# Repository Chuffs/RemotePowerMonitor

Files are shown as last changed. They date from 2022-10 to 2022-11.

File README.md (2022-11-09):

# Remote Power Outage Detection & Alert System
This Github repository and project outlines the usage of an Arduino Based ESP8266 WiFi and Bluetooth Module along with a WaveShare SIM7000E NB-IoT / Cat-M / EDGE / GPRS Module in creating an alert system for a remote site power outage.

---

## Versions
- [V0.1a](#v01a)
- [V0.2a](#v02a) - Current Version
---

## Background
During the summer in outback Queensland, temperatures can exceed 50°C. ALong with the high temperatures weather can be rather sporadic, with sudden flash flooding and lightning storms. This can cause havoc with the electricity network with unplanned outages. A lot of properties in outback Queensland are far from any town and getting notified of a power outage is incredibly rare. In order to avoid rotten food in both fridges and freezers I wanted to create a device that could notify me of a power outage so that I could take appropriate action to save, or at least salvage, food and perishables at these remote locations.

## Initial Drawing of Idea
Simply put we needed a system that could detect the power outage which then alerted some form of microcontroller to then send an alert to myself to notify/warn of the power outage. In order to actually do this, in the case of a power outage, this system would need to be battery operated so that it could continue after power was removed from the site.

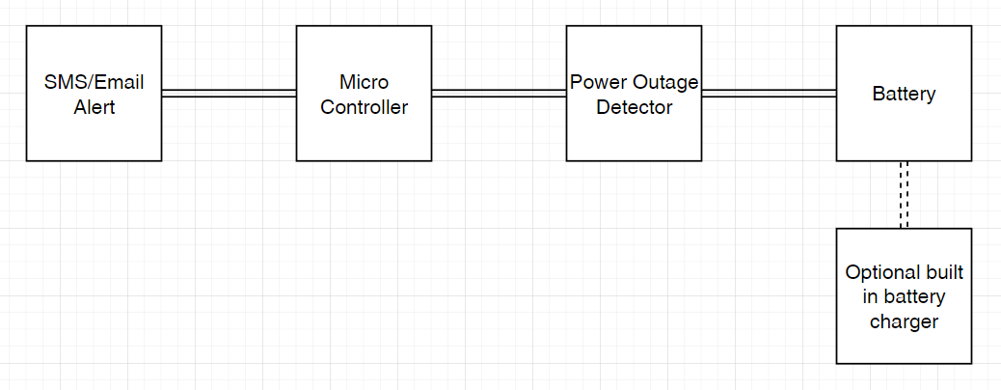
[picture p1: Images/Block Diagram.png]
Block Diagram of Project


# V0.1a
This version used the below components to detect and alert of a power outage.

- [WaveShare SIM7000E][def]
    - *Only LTE Capable module available in Australia at time of purchase*
- [ESP8266 WiFi Board - XC3082][def2]
    - *Small Footprint, Cheap cost and easy to access. Uses the Arduino library and IDE for ease of programming and debugging*
- [XC4502][def4] paired with an [XC4512][def5], a cheap and small footprint LiPo charger and 5v boost module.
- 10k - 10k voltage divider with a 5v Wall Plug into the analog pin of the ESP8266
- Telstra Cat-M SIM Card

## What went well?
- Proof of concept for sending an SMS on an external trigger (analog pin falling below a certain threshold)
- Footprint of prototype, could all be contained within a small jiffy type container.

## ~~Bugs~~ "Features" and what had to be improved on:
- Source of heat in the winter - The XC4502 and the XC4512 cannot be used simultaneously. Loading the battery caused the charger module to think that the battery needed charging and therefore pumped in more voltage causing parts to overheat.
- The usage of the 10k - 10k voltage divider was to ensure that the voltage going into the analog pin didn't exceed the maximum voltage. However, connecting the external 5v and the 5v boost module's ground together caused some strange behavior on the analog to digital conversion in code.
- The price of maintaining a cellular capable SIM was extortionate when considering the usage of this device would probably be a couple times a month during summer or rather 4-6 months of the year.

# V0.2a
This version included a multitude of updates making the system more reliable and user friendly, including a WebUI for configuring and customizing the alerts to be sent. The detection system also had an overhaul and the charging functionality was completely removed.

The code was changed to incorporate the deep sleep functionality of the ESP Family.

One additional part was added in this version - [LiteOn 4N25 Optocoupler][def7]. This allowed the 5v Wall Adapter to be completely separated and isolated from the ESP and Modem.

With testing complete a pcb prototype of this version was made - KiCAD Project Files can be found under this [folder][def8].

## What went well

## What needs improved on

Psuedo code or flow chart was as follows.
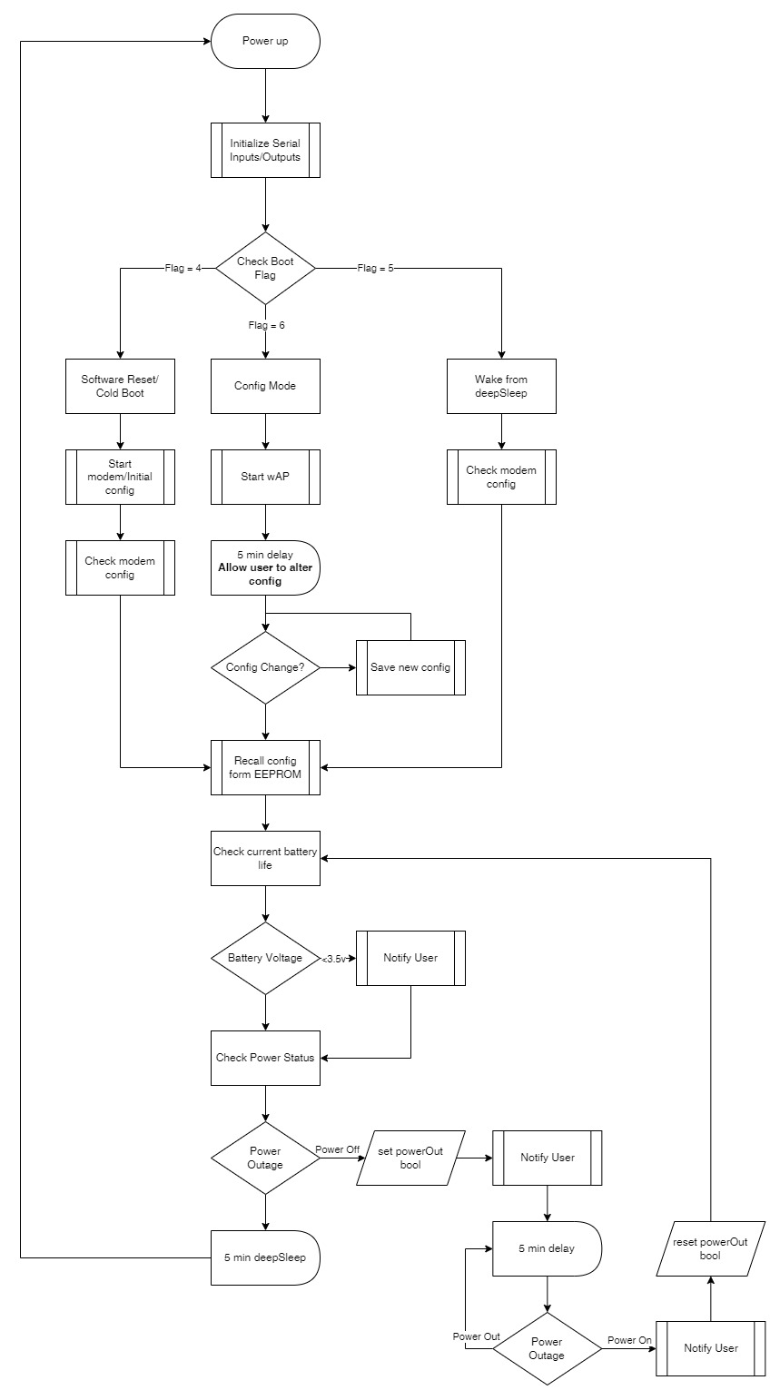
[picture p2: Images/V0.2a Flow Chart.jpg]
Flow Chart of V0.2a


[def]: https://www.waveshare.com/sim7000e-nb-iot-hat.htm
[def2]: https://www.jaycar.com.au/wifi-mini-esp8266-main-board/p/XC3802
[def3]: https://www.kynix.com/editor_u/pdf/20220117/IP5306.pdf
[def4]: https://www.jaycar.com.au/arduino-compatible-lithium-battery-usb-charger-module/p/XC4502
[def5]: https://www.jaycar.com.au/arduino-compatible-5v-dc-to-dc-converter-module/p/XC4512
[def6]: https://www.dfrobot.com/product-1613.html
[def7]: https://au.mouser.com/datasheet/2/239/775704_1-1175530.pdf
[def8]: https://github.com/Chuffs/RemotePowerMonitor/tree/main/v0.2a/v0.2a

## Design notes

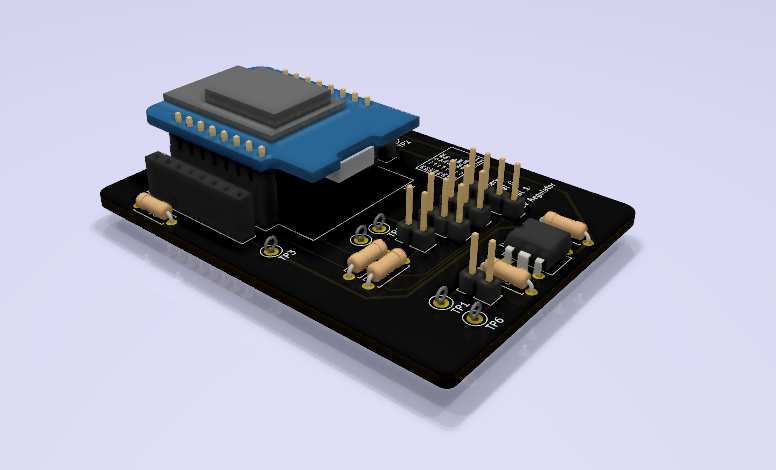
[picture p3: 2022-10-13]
Images/3D_Render_V0.2a.png

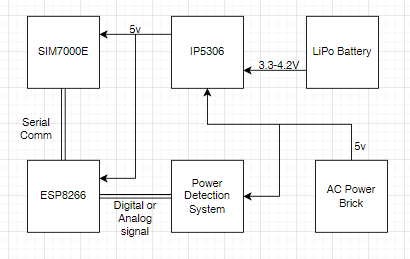
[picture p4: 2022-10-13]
Images/V0.2a Block.png

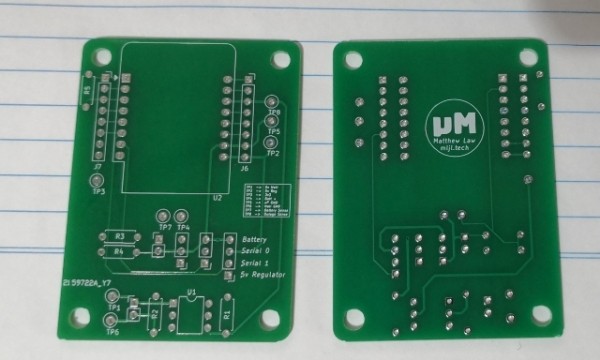
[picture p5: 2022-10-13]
Images/PCB_Prototype_V0.2a.jpg

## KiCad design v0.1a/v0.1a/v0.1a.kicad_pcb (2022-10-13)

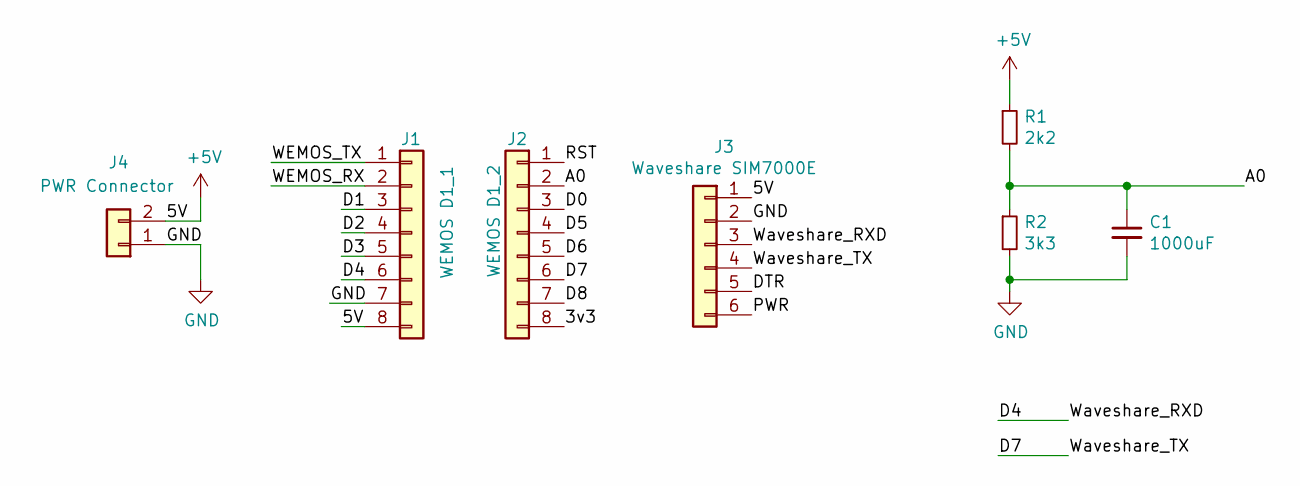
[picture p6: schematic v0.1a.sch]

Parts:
C1: 1000uF; CP_Radial_D10.0mm_P2.50mm_P5.00mm
J1: WEMOS D1_1; PinHeader_1x08_P2.54mm_Vertical
J2: WEMOS D1_2; PinHeader_1x08_P2.54mm_Vertical
J3: Waveshare SIM7000E; PinHeader_1x06_P2.54mm_Vertical
J4: PWR Connector; PinHeader_1x02_P2.54mm_Vertical
R1: 2k2; R_Axial_DIN0411_L9.9mm_D3.6mm_P25.40mm_Horizontal
R2: 3k3; R_Axial_DIN0411_L9.9mm_D3.6mm_P25.40mm_Horizontal

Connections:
+5V: J1.8, J3.1, J4.2, R1.1
/3v3: J2.8
/A0: C1.1, J2.2, R1.2, R2.1
/D0: J2.3
/D1: J1.3
/D2: J1.4
/D3: J1.5
/D4: J1.6, J3.3
/D5: J2.4
/D6: J2.5
/D7: J2.6, J3.4
/D8: J2.7
/DTR: J3.5
/PWR: J3.6
/RST: J2.1
/WEMOS_RX: J1.2
/WEMOS_TX: J1.1
GND: C1.2, J1.7, J3.2, J4.1, R2.2

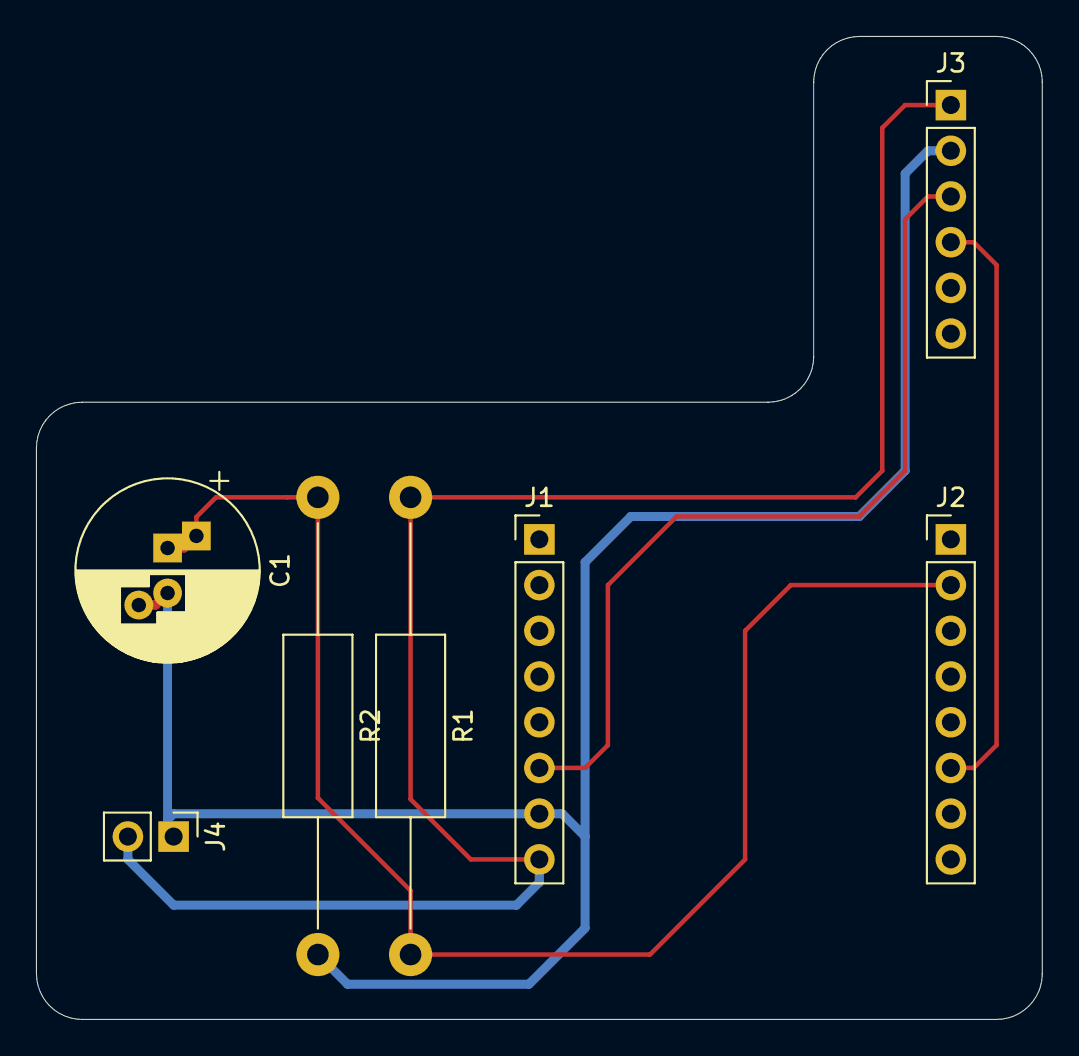
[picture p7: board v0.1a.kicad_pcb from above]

Board: 2 copper layers, 55.9 x 54.6 mm, 7 parts (0 on the bottom side), 5 nets.

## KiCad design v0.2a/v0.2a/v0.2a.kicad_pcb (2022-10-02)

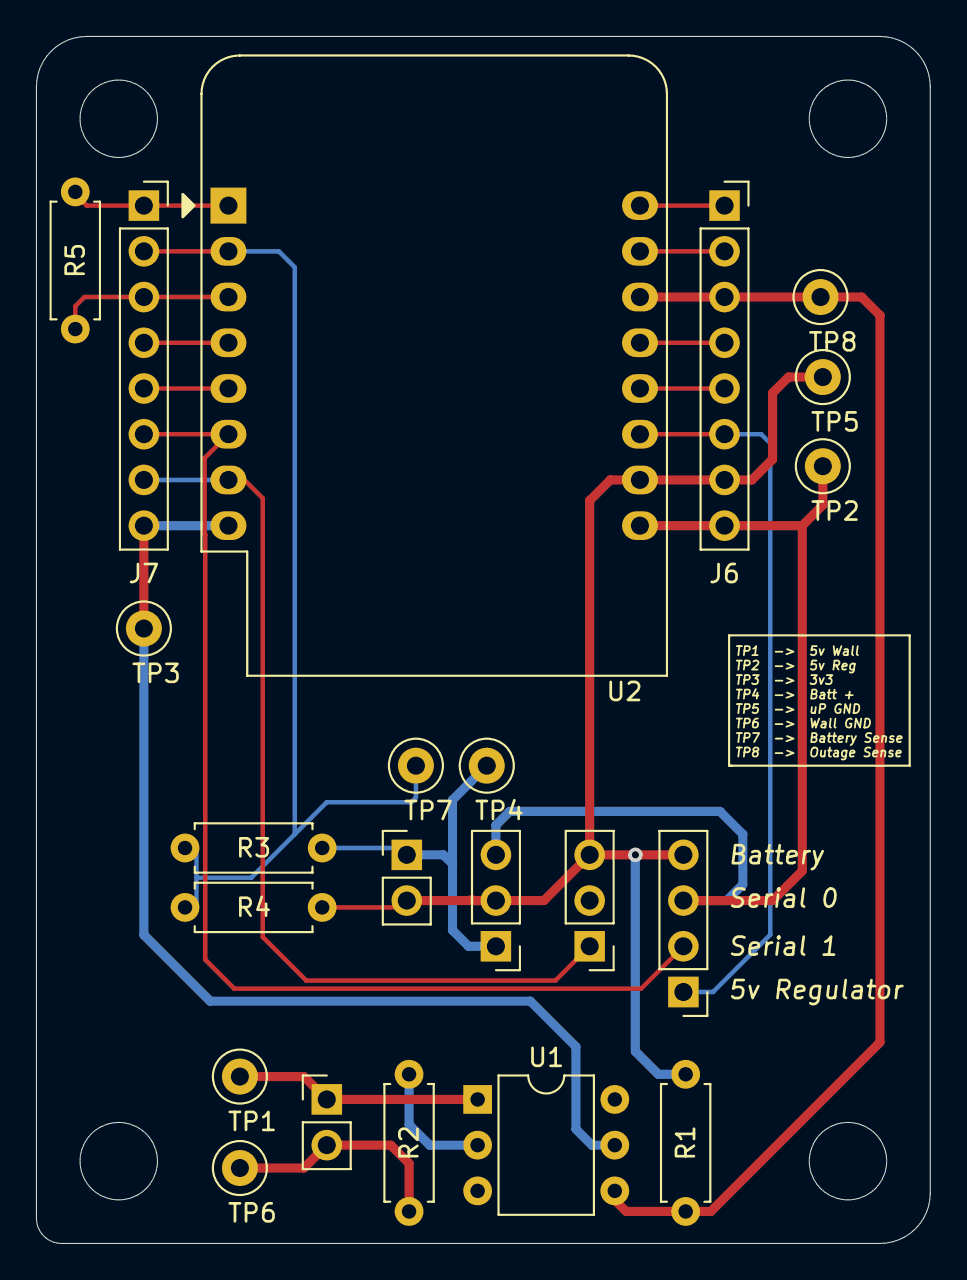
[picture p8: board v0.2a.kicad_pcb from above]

Board: 2 copper layers, 49.7 x 67.1 mm, 22 parts (0 on the bottom side), 20 nets.

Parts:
J1: Battery; PinHeader_1x02_P2.54mm_Vertical
J2: 5v Regulator; PinHeader_1x03_P2.54mm_Vertical
J3: 5v Wall; PinHeader_1x02_P2.54mm_Vertical
J4: Serial 0; PinHeader_1x03_P2.54mm_Vertical
J5: Serial 1; PinHeader_1x04_P2.54mm_Vertical
J6: Wemos RHS; PinSocket_1x08_P2.54mm_Vertical
J7: Wemos LHS; PinSocket_1x08_P2.54mm_Vertical
R1, R3, R4: 10k; R_Axial_DIN0207_L6.3mm_D2.5mm_P7.62mm_Horizontal
R2: 50; R_Axial_DIN0207_L6.3mm_D2.5mm_P7.62mm_Horizontal
R5: 470; R_Axial_DIN0207_L6.3mm_D2.5mm_P7.62mm_Horizontal
TP1: 5v Wall; TestPoint_Loop_D2.50mm_Drill1.0mm_LowProfile
TP2: 5v Regulator; TestPoint_Loop_D2.50mm_Drill1.0mm_LowProfile
TP3: 3v3 Regulator; TestPoint_Loop_D2.50mm_Drill1.0mm_LowProfile
TP4: Battery +; TestPoint_Loop_D2.50mm_Drill1.0mm_LowProfile
TP5: uP GND; TestPoint_Loop_D2.50mm_Drill1.0mm_LowProfile
TP6: Wall GND; TestPoint_Loop_D2.50mm_Drill1.0mm_LowProfile
TP7: Battery_Sense; TestPoint_Loop_D2.50mm_Drill1.0mm_LowProfile
TP8: Outage_Sense; TestPoint_Loop_D2.50mm_Drill1.0mm_LowProfile
U1: 4N25; DIP-6_W7.62mm
U2: WeMos_D1_mini; WEMOS_D1_mini_light

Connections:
+3V3: J7.8, TP3.1, U1.5, U2.8
+5V: J3.1, TP1.1, U1.1
+5VA: J2.3, J5.3, J6.8, TP2.1, U2.9
/A0: J7.2, R3.2, R4.1, TP7.1, U2.2
/Batt+: J1.1, J2.1, R3.1, TP4.1
/Batt-: J1.2, J2.2, J4.3, J5.4, J6.7, R1.2, R4.2, TP5.1, U2.10
/D0: J7.3, R5.1, U2.3
/D1: J6.3, R1.1, TP8.1, U1.4, U2.14
/D2: J6.4, U2.13
/D3: J6.5, U2.12
/D4: J5.1, J6.6, U2.11
/D5: J7.4, U2.4
/D6: J7.5, U2.5
/D7: J5.2, J7.6, U2.6
/D8: J4.1, J7.7, U2.7
/GND_wall: J3.2, R2.2, TP6.1
/RST: J7.1, R5.2, U2.1
/Rx: J6.2, U2.15
/Tx: J6.1, U2.16
unnamed: R2.1, U1.2

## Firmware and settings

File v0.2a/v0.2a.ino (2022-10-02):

/*  Orig. Author:   Matthew Law - mljl.tech
 *  Created:        March 2022
 *  
 *  Power Outage detection and notification for a remote site
 *  
 *  ESP8266 Wemos Mini D1 -
 *  https://escapequotes.net/esp8266-wemos-d1-mini-pins-and-diagram/
 *  Using Waveshare SIM7000E GPRS and GPS Module through serial connection -
 *  https://www.waveshare.com/sim7000e-nb-iot-hat.htm
 *  
 *  Serial Connection Config:
 *      UART0 to receive Data from SIM Module
 *          D7 pin or GPIO 13 (3RHS)
 *      UART1 to send Data to SIM Module 
 *          D4 pin or GPIO 2  (3LHS)
 *   
 *   Includes modifications from the following examples:
 *      https://roboticsbackend.com/arduino-write-string-in-eeprom/
 *      https://microcontrollerslab.com/esp32-esp8266-web-server-input-data-html-forms/
 *      https://forum.arduino.cc/t/esp8266-getresetreason-wrong-result/424689
 *      
 *      Reset Codes:
 *      Code 4 -> Software restart
 *      Code 5 -> Wake from deepSleep
 *      Code 6 -> External Reset - use this to put device into config mode
 * 
 */

#ifdef ESP32
  #include <WiFi.h>
  #include <AsyncTCP.h>
#else
  #include <ESP8266WiFi.h>
  #include <ESPAsyncTCP.h>
#endif
#include <ESPAsyncWebServer.h>

#include <stdio.h>

#define SENSORPIN 14
#define normalDelay 300e6 //5 minutes
#define outageDelay 300e6 //5 minutes

#include <EEPROM.h>

AsyncWebServer server(80);

const char* APSSID = "ESP";

//String funtion to return the status or info from the module
String sendCommand(String command);
//Bool function to check config of Modem is valid & modem is connected to network
bool configModemCheck();
//Function to retry command until an OK status is recieved
void waitForOK(String commmand);
//boolean function if command sent to module *should* return an OK status
bool sendCommandOK(String command);
//Send SMS Payload
void sendSMS(String emailAdd, String loc, float v, String pstat);

float mapf(float x, float in_min, float in_max, float out_min, float out_max);

IPAddress staticIP(192, 168 ,0, 4);
IPAddress gateway(192, 168, 0, 1);
IPAddress subnet(255, 255, 255, 0);

const char* input_parameter1 = "email";
const char* input_parameter2 = "location";

String email, location;

unsigned long previousMillis = 0;
const long interval = 3e5;
//Hologram Cloud API SMS Number
String phonenumber = "447937405250";

const char index_html[] PROGMEM = R"rawliteral(
<!DOCTYPE HTML><html><head>
  <title>Power Outage Detection Config</title>
  <meta name="viewport" content="width=device-width, initial-scale=1">
  <style>
    html {font-family: Times New Roman; display: inline-block; text-align: center;}
    h2 {font-size: 3.0rem; color: black;}
  </style>
  </head><body>
  <h1>Power Outage Detection Config</h1> 
  <form action="/get">
    Email to notify: <input type="text" name="email">
    <input type="submit" value="Submit">
  </form><br>
  <form action="/get">
    Current Location: <input type="text" name="location">
    <input type="submit" value="Submit">
  </form><br>
</body></html>)rawliteral";

void notFound(AsyncWebServerRequest *request) {
  request->send(404, "text/plain", "Not found");
}

void writeStringToEEPROM(int addrOffset, const String &strToWrite) {
  byte len = strToWrite.length();
  EEPROM.write(addrOffset, len);
  EEPROM.commit();
  for (int i = 0; i < len; i++)
  {
    EEPROM.write(addrOffset + 1 + i, strToWrite[i]);
    if (EEPROM.commit()) {
      Serial.println("EEPROM successfully committed");
    } else {
      Serial.println("ERROR! EEPROM commit failed");
    }
  }
}

String readStringFromEEPROM(int addrOffset) {
  int newStrLen = EEPROM.read(addrOffset);
  char data[newStrLen + 1];
  for (int i = 0; i < newStrLen; i++)
  {
    data[i] = EEPROM.read(addrOffset + 1 + i);
  }
  data[newStrLen] = '\0';
  return String(data);
}



void WiFiStart() {
  Serial.print("Setting AP Config: ");
  Serial.println(WiFi.softAPConfig(staticIP, gateway, subnet) ? "Ready!" : "Failed!");

  Serial.print("Setting AP SSID: ");
  Serial.println(WiFi.softAP(APSSID) ? "Ready" : "Failed!");

  Serial.print("IP Address: ");
  Serial.println(WiFi.softAPIP());
  
  server.on("/", HTTP_GET, [](AsyncWebServerRequest *request){
    request->send_P(200, "text/html", index_html);
  });

  server.on("/get", HTTP_GET, [] (AsyncWebServerRequest *request) {
  //Email
    if (request->hasParam(input_parameter1)) {
      email = request->getParam(input_parameter1)->value();
      writeStringToEEPROM(0, email);
    }
  //Location
    else if (request->hasParam(input_parameter2)) {
      location = request->getParam(input_parameter2)->value();
      writeStringToEEPROM(128, location);
    }
    
    request->send(200, "text/html", "Updated!<br><a href=\"/\">Return</a>");
  });
  server.onNotFound(notFound);
  server.begin();
}

void modemStart() {
  //Attention Device and ensure echo is off
  waitForOK("ATE0");
  //Disable Timezone Reporting
  waitForOK("AT+CLTS=0");
  //Enable LTE Mode for SIM
  waitForOK("AT+CNMP=38");
  //Enable CAT-M1 and nb-IoT
  waitForOK("AT+CMNB=1");
  //Enable reporting of network registration status
  waitForOK("AT+CREG=1");
  //Automatically select network operator
  waitForOK("AT+COPS=0");
  //SMS Text Mode
  waitForOK("AT+CMGF=1");
}

void sendPayload(String emailAdd, String loc, float v, String pstat){
  Serial.print("\r###DEBUG: ");
  Serial1.print("{\"email\":\"");
  Serial.print("{\"email\":\"");
  Serial1.print(emailAdd);
  Serial.print(emailAdd);
  Serial1.print("\",\"location\":\"");
  Serial.print("\",\"location\":\"");
  Serial1.print(loc);
  Serial.print(loc);
  Serial1.print("\",\"battery\":\"");
  Serial.print("\",\"battery\":\"");
  Serial1.print(v);
  Serial.print(v);
  Serial1.print("\",\"power_status\":\"");
  Serial.print("\",\"power_status\":\"");
  Serial1.print(pstat);
  Serial.print(pstat);
  Serial1.print("\"}\n\r");
  Serial.print("\"}\n");
}

void setup() {
  Serial.begin(9600);
  while(!Serial);
  Serial.swap();
  Serial.println("Serial Ready!");

  Serial1.begin(9600);
  while(!Serial1);
  Serial.println("Serial 1 Ready!");
  
  EEPROM.begin(512);

  pinMode(SENSORPIN, INPUT);

  rst_info *resetInfo;
  resetInfo = ESP.getResetInfoPtr();

  Serial.print("Reset Code = ");
  Serial.println(resetInfo->reason);

  if(resetInfo->reason == 6) {
    bool flag = true;
    WiFiStart();    
    } else if (resetInfo->reason == 4) {
    modemStart();
  }

  email = readStringFromEEPROM(0);
  location = readStringFromEEPROM(128);
  String configDetails = "Email address to notify: " + email + ", reporting Location as: " + location + ".";
  Serial.println(configDetails);

  delay(500);

  modemStart();

//  while(1) {
//    bool flag = configModemCheck();
//    delay(500);
//    Serial.print("Checking Modem Config: ");
//    if(!flag) {
//      modemStart();
//    } else {
//      break;
//    }
//  }
}

void loop() {
  // What is the current battery level?
  float vbat = mapf(analogRead(A0)*2, 0, 1024, 0, 3.2);
  delay(500);
  Serial.print("Current Detection Voltage = ");
  Serial.println(vbat);
  // if battery is ~3.5, battery is running low, notify user
  if(vbat <= 3.50) {
    //Send SMS
    sendSMS(email, location, vbat, "normal");
  }
  delay(500);
  Serial.print("Checking Power Status: ");
  Serial.println(digitalRead(SENSORPIN) ? "Normal" : "Outage");
  // Check IR Sensor/DC Power
  if(digitalRead(SENSORPIN) == false ) {
    //Power Outage
    Serial.println("###DEBUG: POWER OUTAGE DETECTED");
    //Send SMS
    //Construct Payload
    // void sendSMS(String emailAdd, String loc, float v, String pstat);
    sendSMS(email, location, vbat, "Outage");
    bool powerOut = true;
    while(powerOut) {
      delay(500); //Every 5 minutes
      powerOut = digitalRead(SENSORPIN) ? false : true;
    }
    //If we get here, power has been restored
    Serial.println("###DEBUG: POWER RESTORED");
    //Send SMS
    sendSMS(email, location, vbat, "Restored");
  } else {
    unsigned long currentMillis = millis();
    if(currentMillis - previousMillis >= interval) {
      previousMillis = currentMillis;
      ESP.deepSleep(normalDelay);
    }
    yield();
  }
}

String sendCommand(String command) {
  String response;
  char incomingChar;
  char error[8] = {'E','R','R','O','R','\r','\n','\0'};
  
  delay(500);
  Serial1.println(command);
  Serial.print("\rCommand Sent: ");
  Serial.println(command);

  delay(500);
  while(Serial.available()) {
    incomingChar = Serial.read();
    response.concat(incomingChar);
    Serial.print(incomingChar,DEC);
    Serial.print(",");
  }

  if(response == ""){
    Serial.println("No Response");
    return String("Error");
  }

  response = response.substring(2,response.length());
  
  return response;
}

bool configModemCheck() {
  String signalStr;
  int signalResponse[2];

  signalStr = sendCommand("AT+CREG?\n\r");

  delay(500);
  Serial.println(signalStr);
  
  //Response will be +CREG:x,x - remove +CREG: so we are left with valuable info
  signalStr = signalStr.substring(7, signalStr.length()-8);

  //Convert from ASCII to decimal numbers
  signalResponse[0] = (int)signalStr[0] - 48;
  signalResponse[1] = (int)signalStr[2] - 48;

  //DEBUG
  Serial.print("\nsignalResponse[0] = ");
  Serial.println(signalResponse[0]);
  Serial.print("signalResponse[1] = ");
  Serial.println(signalResponse[1]);
  
  //Check if modem is connected to Home network or is roaming
  if(signalResponse[1] == 1 | signalResponse[1] == 5) {
    Serial.println("Connected to a Network - SMS Opperational");
    return true;
  } else if(signalResponse[1] == 0) {
    Serial.println("Modem not searching for new network, reset device...");
    ESP.restart();
  } else if(signalResponse[1] == 2) {
    Serial.println("Modem still searching for network to attach to, sleeping...");
    ESP.deepSleep(60e6);
  } else {
    Serial.println("No Response");
    return false;
  }
}

void waitForOK(String command) {
  int delay_val = 1;
  int cmd_sent = 1;
  while(cmd_sent) {
    if(sendCommandOK(command)){
      // Recieved correct data from SIM Module
      cmd_sent = 0;
      return;
    } else {
      // Nothing returned from SIM Module, try again
      Serial.printf(" from module, trying again in %d seconds\n", delay_val);
    if(delay_val < 10) {
      delay_val++;
    }
    delay(delay_val*1000);
    }
  }
}

bool sendCommandOK(String command) {
  int incomingByte = 0;
  String response;
  char expected[5] = {'O', 'K', '\r', '\n', '\0'};
  char incomingChar;

//Send command to module on Serial1, repeat command to debug on Serial
  Serial1.println(command);
  Serial.print("\rCommand Sent: ");
  Serial.println(command);

  delay(500);
  while(Serial.available() > 0) {
    incomingChar = Serial.read();
    response.concat(incomingChar);
  }

//Check to see if we actually got anything from Serial
  if(response == ""){
    Serial.print("No Response");
//    Serial.println(response);
    return false;
  }

//Remove \r and \n from from begining of response
  response = response.substring(2,response.length());

//  For debug purposes, print ASCII code of chars in response
  for(int i = 0; i < response.length(); i++) {
    Serial.print(response[i],DEC);
    Serial.print(",");
  }
  Serial.print(response);

  if(response == expected) {
    Serial.print(" - Success!\n");
    return true;
  } else {
    Serial.print(" - FAIL\n");
    //Usually paired with waitForOK subroutine, so will try again in 1-10 seconds
    return false;
  }
}


void sendSMS(String emailAdd, String loc, float v, String pstat) {
  char CTRL_Z = '';
  String command;
  String response;
  int incomingChar;

  //String phonenumber = "447937405250";
  Serial1.println("AT+CMGS=\"447937405250\"\n\r");
  Serial.print("Command sent: AT+CMGS=\"447937405250\"\n\r");

  delay(500);

  Serial.print("\r###DEBUG: ");
  Serial1.print("{\"email\":\"");
  Serial.print("{\"email\":\"");
  Serial1.print(emailAdd);
  Serial.print(emailAdd);
  Serial1.print("\",\"location\":\"");
  Serial.print("\",\"location\":\"");
  Serial1.print(loc);
  Serial.print(loc);
  Serial1.print("\",\"battery\":\"");
  Serial.print("\",\"battery\":\"");
  Serial1.print(v);
  Serial.print(v);
  Serial1.print("\",\"power_status\":\"");
  Serial.print("\",\"power_status\":\"");
  Serial1.print(pstat);
  Serial.print(pstat);
  Serial1.print("\"}\n\r");
  Serial.print("\"}\n");

  Serial1.print((char)26);
  Serial1.print("\n\r");

  Serial.println((char)26);

  return;
}

float mapf(float x, float in_min, float in_max, float out_min, float out_max) {
  return (x - in_min) * (out_max - out_min) / (in_max - in_min) + out_min;
}

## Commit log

2022-10-02 Gerber File Creation
    [v0.2a-B_Cu.gbr, v0.2a-B_Mask.gbr, v0.2a-B_Paste.gbr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]
2022-10-03 gitignore update
    [v0.2a-B_Cu.gbr, v0.2a-B_Mask.gbr, v0.2a-B_Paste.gbr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]
2022-10-13 Stashed v0.1a
    [v0.1a.kicad_pcb, v0.1a.sch]
2022-10-22 KiCad Update
    Updated files to v6 KiCad
